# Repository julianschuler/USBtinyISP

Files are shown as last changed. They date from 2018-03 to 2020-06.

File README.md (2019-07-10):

# USBtinyISP
## Introduction
The USBtinyISP is an USB AVR ISP programmer, capable of writing and reading flash, EEPROM and fuse bits of Atmel AVRs. It is based on the [USBtiny project](https://dicks.home.xs4all.nl/avr/usbtiny/index.html) by Dick Streefland and can be used as the [USBtinyISP](https://www.adafruit.com/product/46) by Adafruit, therefore it works great with avrdude und AVRStudio!

## Features
The USBtinyISP is due to the usage of the ATtiny24A as main controller extremely small and low cost, it has the form factor and size of a general USB Stick and offers a standard 6 pin ISP connector.
This programmer is able to power the target board with up to 300mA @ 3.3V or 500mA @ 5V, selectable via DIP switches (see [How to use](#how-to-use) for further information). If power distribution is deactivated, the target AVR will be programmed with with a voltage level equal to the voltage applied by the target board to the VCC pin of the ISP. This means, e. g. a battery powered project running at a voltage anywhere around 3.7V will be programmed with the same voltage level, this way you don't have to worry about destroying your AVR by programming it with a voltage higher than the supply voltage!

## How to use
With the first DIP switch the target power distribution can be activated (ON ≙ activated, OFF ≙ deactivated), the second one selects the supply voltage (ON ≙ 5V, OFF ≙ 3.3V).The USBtinyISP runs under Windows, Linux and MacOS X, for Windows a [modified LibUSB driver](http://www.adafruit.com/downloads/usbtiny_signed_8.zip) has to be installed. It can be used with avrdude by including the option `-c usbtiny`, within the Arduino IDE `Tools > Programmer: "USBtinyISP"` has to be selected. 
Other than that the USBtinyISP just has to plugged into an USB port and connected with an standard 6 pin ISP cable to the target board!

## License
This project is licensed under GNU GPLv3, see [`LICENSE.txt`](LICENSE.txt) for further information.

## Todo
- Add build instructions
- Add pictures

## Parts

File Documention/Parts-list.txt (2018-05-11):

Qty.	Part name				Package
-------------------------------------
1x		ATtiny24A 				SOIC-14
1x		TLV70233 				SOT-23-5
2x		AO 3415A				SOT-23
1x		BC847B					SOT-23
1x		BC847BS					SOT-363
1x		BC857BS					SOT-363
1x		LL4148					MiniMELF
2x		3.6V Zener diode		MiniMELF
1x		12MHz crystal			HC49-US
2x		22pF capacitor			SMD 1206
1x		100nF capacitor			SMD 1206
2x		10µF capacitor			SMD 1206
2x		68Ω resistor			SMD 1206
5x		1kΩ resistor			SMD 1206
1x		2.2kΩ resistor			SMD 1206
3x		10kΩ resistor			SMD 1206
1x		LED green				SMD 3216 (1206)
1x		LED red					SMD 3216 (1206)
1x		USB-A male plug			SMD
1x		DIP switches 2x			THT
1x		Shrouded header 6 pin	THT

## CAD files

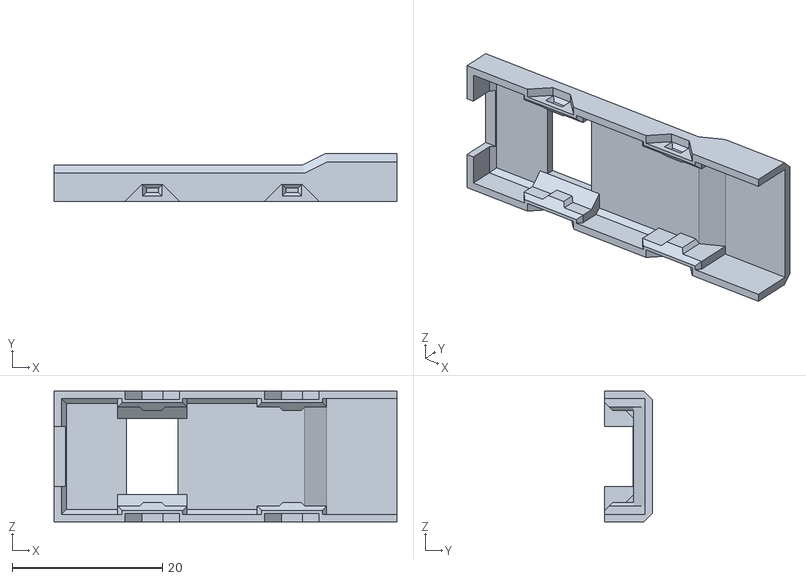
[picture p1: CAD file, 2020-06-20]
Case/Case-USBtinyISP-Top.stl
45.7 x 6.35 x 17.4

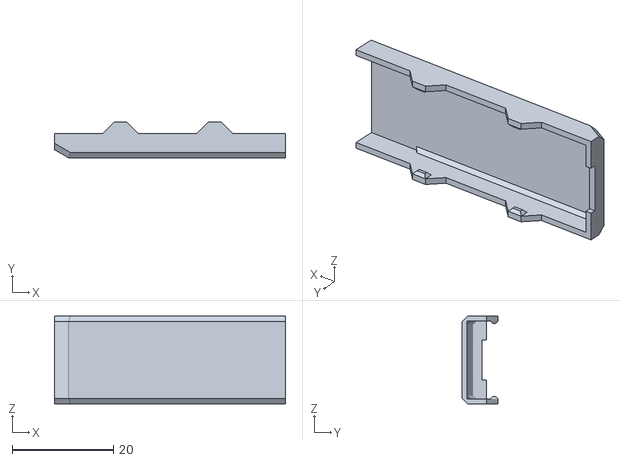
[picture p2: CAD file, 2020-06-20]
Case/Case-USBtinyISP-Bottom.stl
45.7 x 7.10 x 17.4

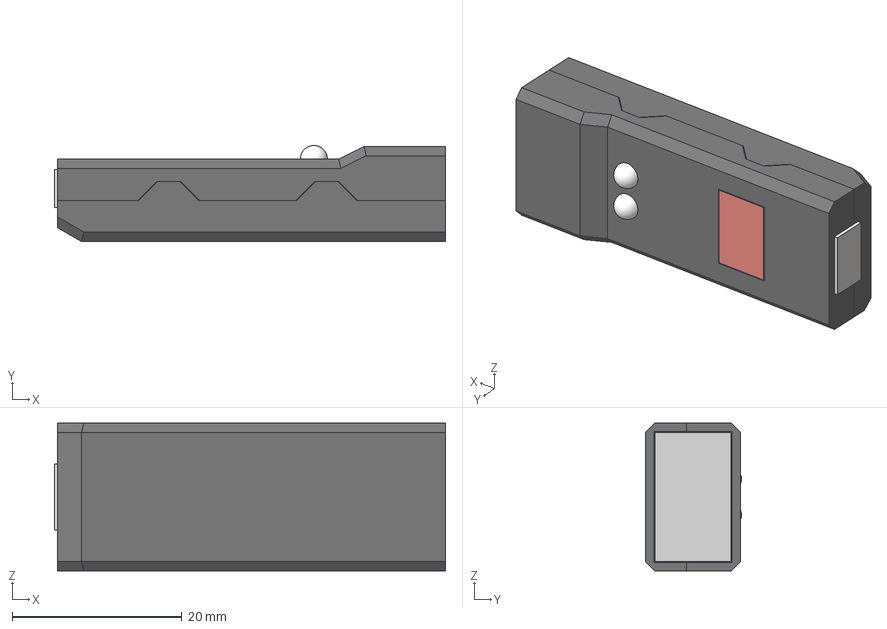
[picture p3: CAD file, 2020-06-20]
Case/Case-USBtinyISP.step
46.1 x 11.3 x 17.4 mm

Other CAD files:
Case/Case-USBtinyISP.3mf
Case/Case-USBtinyISP.f3d

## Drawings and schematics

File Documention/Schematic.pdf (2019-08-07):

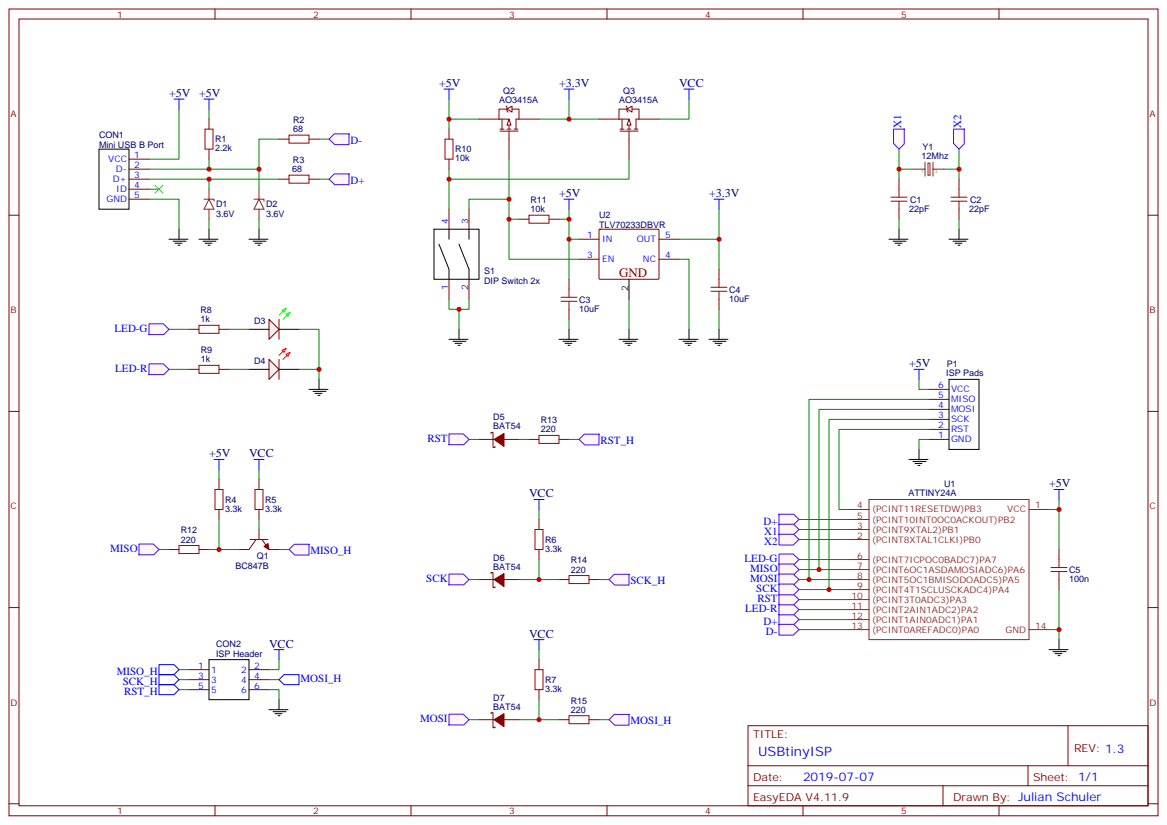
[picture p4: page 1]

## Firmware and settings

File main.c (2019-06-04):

// ======================================================================
// main.c
//
// This file is a part of the ATtiny24A based USBtinyISP project
// by Julian Schuler (https://github.com/julianschuler/usbtinyisp).
//
// It is based on the USBtiny project by Dick Streefland
// (https://dicks.home.xs4all.nl/avr/usbtiny/index.html)
//
// Copyright (C) 2006-2010 Dick Streefland
// Copyright (C) 2018 Julian Schuler
//
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

#include <avr/io.h>
#include <avr/interrupt.h>
#include <def.h>
#include <usb.h>

#define USE_OLD_PCB		1	//necessary due to an unintended pin switch between MOSI and SCK, will be removed after a new PCB has been created
#define USE_USI_SPI		1	//set to 1 to use USI for SPI, limited to DO, DI and USCK pins for MOSI, MISO and SCK


// ----------------------------------------------------------------------
// I/O pins:
// ----------------------------------------------------------------------
#define	PORT		PORTA
#define	DDR			DDRA
#define	PIN			PINA

#define	LED			PA2		// output
#define	RESET		PA3		// output
#define	MISO		PA6		// input

#if USE_OLD_PCB
#define	MOSI		PA4		// output
#define	SCK			PA5		// output
#else
#define	MOSI		PA5		// output
#define	SCK			PA4		// output
#endif

#define	LED_MASK	_BV(LED)
#define	RESET_MASK	_BV(RESET)
#define	MOSI_MASK	_BV(MOSI)
#define	MISO_MASK	_BV(MISO)
#define	SCK_MASK	_BV(SCK)


#if USE_OLD_PCB
#undef USE_USI_SPI
#define USE_USI_SPI	 	0	//USI SPI only usable with new PCB
#endif


enum {
	// Generic requests
	USBTINY_ECHO,			// echo test
	USBTINY_READ,			// read byte
	USBTINY_WRITE,			// write byte
	USBTINY_CLR,			// clear bit 
	USBTINY_SET,			// set bit
	
	// Programming requests
	USBTINY_POWERUP,		// apply power (wValue:SCK-period, wIndex:RESET)
	USBTINY_POWERDOWN,		// remove power from chip
	USBTINY_SPI,			// issue SPI command (wValue:c1c0, wIndex:c3c2)
	USBTINY_POLL_BYTES,		// set poll bytes for write (wValue:p1p2)
	USBTINY_FLASH_READ,		// read flash (wIndex:address)
	USBTINY_FLASH_WRITE,	// write flash (wIndex:address, wValue:timeout)
	USBTINY_EEPROM_READ,	// read eeprom (wIndex:address)
	USBTINY_EEPROM_WRITE,	// write eeprom (wIndex:address, wValue:timeout)
	USBTINY_DDRWRITE,		// set port direction
	USBTINY_SPI1			// a single SPI command
};


// ----------------------------------------------------------------------
// Local data
// ----------------------------------------------------------------------
static uint8_t		sck_period;	// SCK period in microseconds (1..250)
static uint8_t		poll1;		// first poll byte for write
static uint8_t		poll2;		// second poll byte for write
static uint16_t		address;	// read/write address
static uint16_t		timeout;	// write timeout in usec
static uint8_t		cmd0;		// current read/write command byte
static uint8_t		cmd[4];		// SPI command buffer
static uint8_t		res[4];		// SPI result buffer

// ----------------------------------------------------------------------
// Delay exactly <sck_period> times 0.5 microseconds (6 cycles).
// ----------------------------------------------------------------------
__attribute__((always_inline))
static inline void delay(void) {
	asm volatile(
		"	mov	__tmp_reg__,%0	\n"
		"0:	rjmp	1f		\n"
		"1:	dec	__tmp_reg__	\n"
		"	brne	0b		\n"
		: : "r" (sck_period) );
}


// ----------------------------------------------------------------------
// Issue one SPI command.
// ----------------------------------------------------------------------
static void spi(uint8_t* cmd, uint8_t* res, uint8_t n) {
	uint8_t	c;
	#if !USE_USI_SPI
	uint8_t	r;
	uint8_t	mask;
	#endif
	
	while (n != 0) {
		n--;
		c = *cmd++;
		
		#if USE_USI_SPI
		USIDR = c;
		USISR = 1 << USIOIF;

		while ((USISR & (1<<USIOIF)) == 0) {
			USICR = (1<<USIWM0) | (1<<USICS1) | (1<<USICLK) | (1<<USITC);
			delay();
		}

		*res++ = USIDR;
		#else
		r = 0;
		//cli();
		for (mask = 0x80; mask; mask >>= 1) {
			if (c & mask) {
				PORT |= MOSI_MASK;
			}
			else {
				PORT &= ~MOSI_MASK;
			}
			delay();
			PORT |= SCK_MASK;
			//PORT |= LED_MASK;
			delay();
			r <<= 1;
			if (PIN & MISO_MASK) {
				r++;
			}
			PORT &= ~SCK_MASK;
			//PORT &= ~LED_MASK;
		}
		*res++ = r;
		//sei();
		#endif
	}
}

// ----------------------------------------------------------------------
// Create and issue a read or write SPI command.
// ----------------------------------------------------------------------
static void spi_rw (void) {
	uint16_t a;
	
	a = address++;
	if (cmd0 & 0x80) {	// eeprom
		a <<= 1;
	}
	cmd[0] = cmd0;
	if (a & 1) {
		cmd[0] |= 0x08;
	}
	cmd[1] = a >> 9;
	cmd[2] = a >> 1;
	spi(cmd, res, 4);
}

// ----------------------------------------------------------------------
// Handle a non-standard SETUP packet.
// ----------------------------------------------------------------------
extern uint8_t usb_setup (uint8_t data[8]) {
	uint8_t req = data[1];
	uint8_t mask;
	
	// Generic requests
	if (req == USBTINY_ECHO) {
		return 8;
	}
	if (req == USBTINY_READ) {
		data[0] = PIN;
		return 1;
	}
	if (req == USBTINY_WRITE || req == USBTINY_CLR || req == USBTINY_SET || req == USBTINY_DDRWRITE) {
		return 0;
	}
	
	// Programming requests
	if (req == USBTINY_POWERUP) {
		sck_period = data[2];
		mask = 0;
		mask = LED_MASK;
		if (data[4]) {
			mask |= RESET_MASK;
		}
		DDR  |= LED_MASK | RESET_MASK | SCK_MASK | MOSI_MASK;
		PORT |= mask;
		return 0;
	}
	
	if (req == USBTINY_POWERDOWN) {
		DDR  &= ~(LED_MASK | RESET_MASK | SCK_MASK | MOSI_MASK);
		PORT &= ~(LED_MASK | RESET_MASK | SCK_MASK | MOSI_MASK);
		return 0;
	}
	if (!PORT) {
		return 0;
	}
	if (req == USBTINY_SPI) {
		spi(data + 2, data + 0, 4);
		return 4;
	}
	if (req == USBTINY_SPI1) {
		spi(data + 2, data + 0, 1);
		return 1;
	}
	if (req == USBTINY_POLL_BYTES) {
		poll1 = data[2];
		poll2 = data[3];
		return 0;
	}
	address = * (uint16_t*) & data[4];
	if (req == USBTINY_FLASH_READ) {
		cmd0 = 0x20;
		return 0xff;	// usb_in() will be called to get the data
	}
	if (req == USBTINY_EEPROM_READ) {
		cmd0 = 0xa0;
		return 0xff;	// usb_in() will be called to get the data
	}
	timeout = * (uint16_t*) & data[2];
	if (req == USBTINY_FLASH_WRITE) {
		cmd0 = 0x40;
		return 0;	// data will be received by usb_out()
	}
	if (req == USBTINY_EEPROM_WRITE) {
		cmd0 = 0xc0;
		return 0;	// data will be received by usb_out()
	}
	return 0;
}

// ----------------------------------------------------------------------
// Handle an IN packet.
// ----------------------------------------------------------------------
extern	uint8_t	usb_in(uint8_t* data, uint8_t len) {
	uint8_t	i;
	
	for (i = 0; i < len; i++) {
		spi_rw();
		data[i] = res[3];
	}
	return len;
}

// ----------------------------------------------------------------------
// Handle an OUT packet.
// ----------------------------------------------------------------------
extern void usb_out(uint8_t* data, uint8_t len) {
	uint8_t i;
	uint16_t usec;
	uint8_t r;
	
	for	(i = 0; i < len; i++) {
		cmd[3] = data[i];
		spi_rw();
		cmd[0] ^= 0x60;	// turn write into read
		for	(usec = 0; usec < timeout; usec += 32 * sck_period) {	// when timeout > 0, poll until byte is written
			spi(cmd, res, 4);
			r = res[3];
			if (r == cmd[3] && r != poll1 && r != poll2) {
				break;
			}
		}
	}
}

// ----------------------------------------------------------------------
// Main
// ----------------------------------------------------------------------
extern int main ( void ) {
	usb_init();
	while (1) {
		usb_poll();
	}
}

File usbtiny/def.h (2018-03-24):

// ======================================================================
// Common definitions for the USB driver
//
// Copyright 2006-2010 Dick Streefland
//
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

#ifdef __ASSEMBLER__
	#define __SFR_OFFSET		0
#endif

#include <avr/io.h>
#include "usbtiny.h"

// Preprocessor magic
#define CAT2(a,b)				CAT2EXP(a, b)
#define CAT2EXP(a,b)			a ## b
#define CAT3(a,b,c)				CAT3EXP(a, b, c)
#define CAT3EXP(a,b,c)			a ## b ## c

// I/O Ports for USB
#define USB_IN					CAT2(PIN, USBTINY_PORT)
#define	USB_OUT					CAT2(PORT, USBTINY_PORT)
#define	USB_DDR					CAT2(DDR, USBTINY_PORT)

// I/O bit masks for USB
#define USB_MASK_DMINUS			(1 << (USBTINY_DMINUS))
#define USB_MASK_DPLUS			(1 << (USBTINY_DPLUS))
#define USB_MASK				(USB_MASK_DMINUS | USB_MASK_DPLUS)

// Interrupt configuration
#if defined EICRA
	#define USB_INT_CONFIG		EICRA
#else
	#define USB_INT_CONFIG		MCUCR
#endif
#define USB_INT_CONFIG_SET		((1 << CAT3(ISC,USBTINY_INT,1)) | (1 << CAT3(ISC,USBTINY_INT,0)))
#define USB_INT_VECTOR			CAT3(INT, USBTINY_INT, _vect)

// Interrupt enable
#if defined GIMSK
	#define USB_INT_ENABLE		GIMSK
#elif defined EIMSK
	#define USB_INT_ENABLE		EIMSK
#else
	#define USB_INT_ENABLE		GICR
#endif
#define USB_INT_ENABLE_BIT		CAT2(INT,USBTINY_INT)

// Interrupt pending bit
#if defined EIFR
	#define USB_INT_PENDING		EIFR
#else
	#define USB_INT_PENDING		GIFR
#endif
#define USB_INT_PENDING_BIT		CAT2(INTF,USBTINY_INT)
#if defined INF0 && ! defined INTF0
#  define INTF0					INF0	// fix for incorrect definition in iotn13.h
#endif

// USB PID values
#define	USB_PID_SETUP			0x2d
#define	USB_PID_OUT				0xe1
#define	USB_PID_IN				0x69
#define	USB_PID_DATA0			0xc3
#define	USB_PID_DATA1			0x4b
#define	USB_PID_ACK				0xd2
#define	USB_PID_NAK				0x5a
#define	USB_PID_STALL			0x1e

// Various constants
#define	USB_BUFSIZE				11	// PID + data + CRC

// Bit manipulation macros
#define	BIT_CLR(reg,bit)		{ (reg) &= ~ _BV(bit); }
#define	BIT_SET(reg,bit)		{ (reg) |=   _BV(bit); }
#define	BIT_TST(reg,bit)		(((reg) & _BV(bit)) != 0)

// I/O port manipulation macros
#define	DDR_CLR(p,b)			BIT_CLR(DDR  ## p, b)
#define	DDR_SET(p,b)			BIT_SET(DDR  ## p, b)
#define	PORT_CLR(p,b)			BIT_CLR(PORT ## p, b)
#define	PORT_SET(p,b)			BIT_SET(PORT ## p, b)
#define	PORT_TST(p,b)			BIT_TST(PORT ## p, b)
#define	PIN_TST(p,b)			BIT_TST(PIN  ## p, b)
#define	PIN_SET(p,b)			BIT_SET(PIN  ## p, b)

// Macros that can be used with an argument of the form (port,bit)
#define	INPUT(bit)				DDR_CLR bit
#define	OUTPUT(bit)				DDR_SET bit
#define	CLR(bit)				PORT_CLR bit
#define	SET(bit)				PORT_SET bit
#define	ISSET(bit)				PORT_TST bit
#define	TST(bit)				PIN_TST bit
#define	TOGGLE(bit)				PIN_SET bit

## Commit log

2018-03-24 Fixed bugs & minor changes
    [def.h, main.c]
2018-03-26 Added parts list and moved schematic
    [Parts-list-Reichelt.csv]
2019-06-04 Add USI for SPI communication and workaround for incorrect PCB design
    [main.c]
2019-07-10 Create new schematic, PCB and parts list
    [Parts-list-Reichelt.csv]
2019-08-07 Replace USB A plug with USB Mini B port
    By replacing the USB A plug with a USB Mini B port the USBtinyISP can be used further away from the PC by using a common USB Mini B cable with the desired length
    [Parts-list-Reichelt.csv]
2019-09-12 Minor PCB cleanup
2020-06-20 Add case files
    [Case-USBtinyISP-Bottom.stl, Case-USBtinyISP-Top.stl, Case-USBtinyISP.3mf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]

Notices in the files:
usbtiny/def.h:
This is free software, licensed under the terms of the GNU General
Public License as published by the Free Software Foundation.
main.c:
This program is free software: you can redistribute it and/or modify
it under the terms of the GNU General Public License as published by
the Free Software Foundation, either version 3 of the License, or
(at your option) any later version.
